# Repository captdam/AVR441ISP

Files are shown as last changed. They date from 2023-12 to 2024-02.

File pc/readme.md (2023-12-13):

# ISP PC software

This software will open a TCP server to interactive with user and a TTY (UART) connection to interactive with ISP.

## Client-side

This software use webpage to serve the client-side GUI to reduce UI related code and compute on this software. The server-side of this software will host a mini webserver on a localhost port. User can use web browser to access the client-side program.

Using webpage (HTML + CSS + JS) not only making the GUI programming easier compare to using other methods, but also give the user the ability to customlize the UI and workflow. Users are welcome to modify any of the HTML, JS and CSS files. It is also possbile to open the server port to network for remote programming.

There is no need to compile the client-side code, web browser does this on-the-fly, and they are not slow (for modern PC).

## Server

The server-side of this software is in fact a simple HTTP server and a UART translator.

GET request from client-side via XHR lets the server to return webpage related resources, such as HTML file, JS file...

POST / PUT request lets the server to translate the request from HTTP to UART and relay the request to the ISP. After ISP response, the server return the response to the client.

DELETE request halts the software.

Compile with ```gcc *.c -O2 -o isp```.

## Execute

First, connect the ISP to PC.

Execute with ```./isp tty port``` where ```tty``` is the UART device and ```port``` is the port number to open server. Example: ```./isp /dev/ttyUSB0 10086```.

Use web browser (I use Firefox for dev) and go to ```localhost:port``` where ```port``` is same as the previous step. Example: ```localhost:10086```. You may open page inspector to see some logs in console. This will send a ```GET``` request to the server to get the client-side software from the server. A blank page then displayed in the web browser, the server-side software also says "Request index page".

Click any button on this page will send ```PUT``` request to the server. The server will translate the request from HTTP to UART and send it to the ISP. After ISP response, the data from ISP in UART will be translated into HTTP response body and returned back to the client.

The first step is to use "SPI Get" to enable programming and read signature bytes from the target AVR. If the signature matches with a known one in the configuration JSON, this software will display a table of the NVME of the target AVR. Use "X READ" to read each of them (example, read hfuse), the software will read the specific data from the target AVR and display them in the table.

To porperly close the software, use the "Halt". This will send a ```DELETE``` request which request the server to exit (this performs some house-cleanning before exit). After this operation, you must restart the server-side software and refresh the client-side page to use this software again.

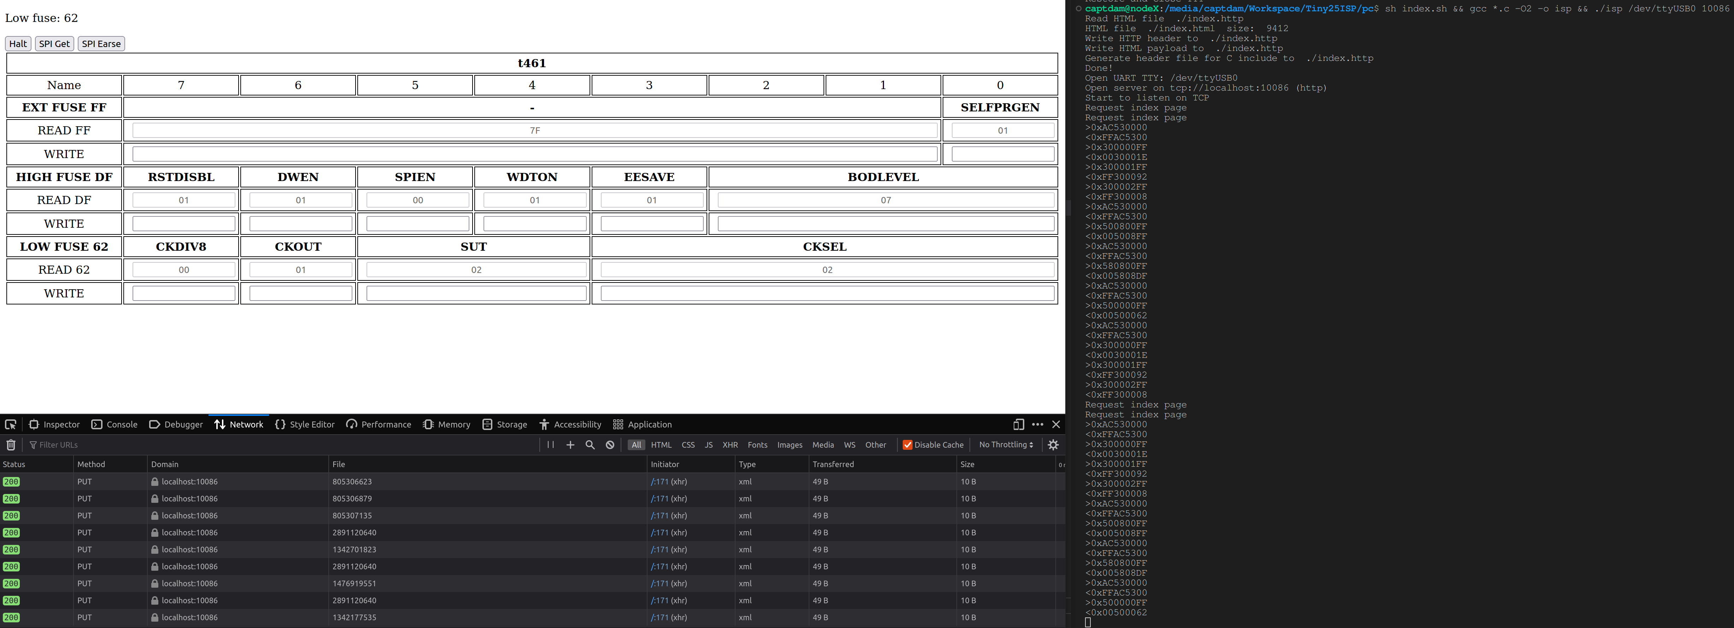
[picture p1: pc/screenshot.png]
Program running


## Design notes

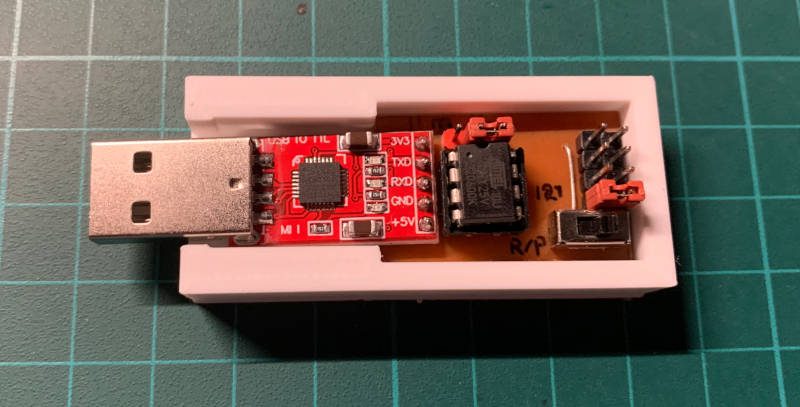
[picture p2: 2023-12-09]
isp/photo-frontside.jpeg

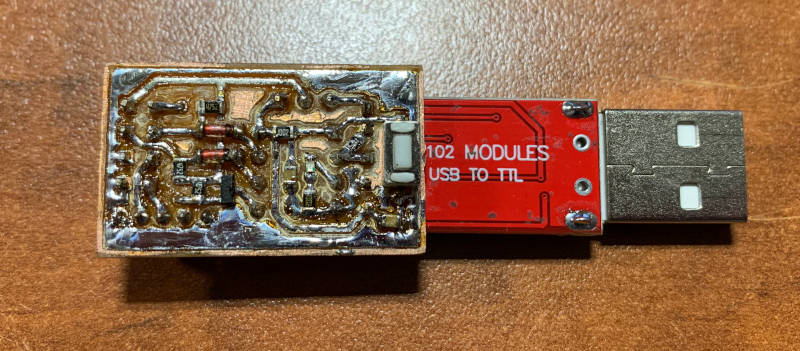
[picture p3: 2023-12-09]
isp/photo-backside.jpeg

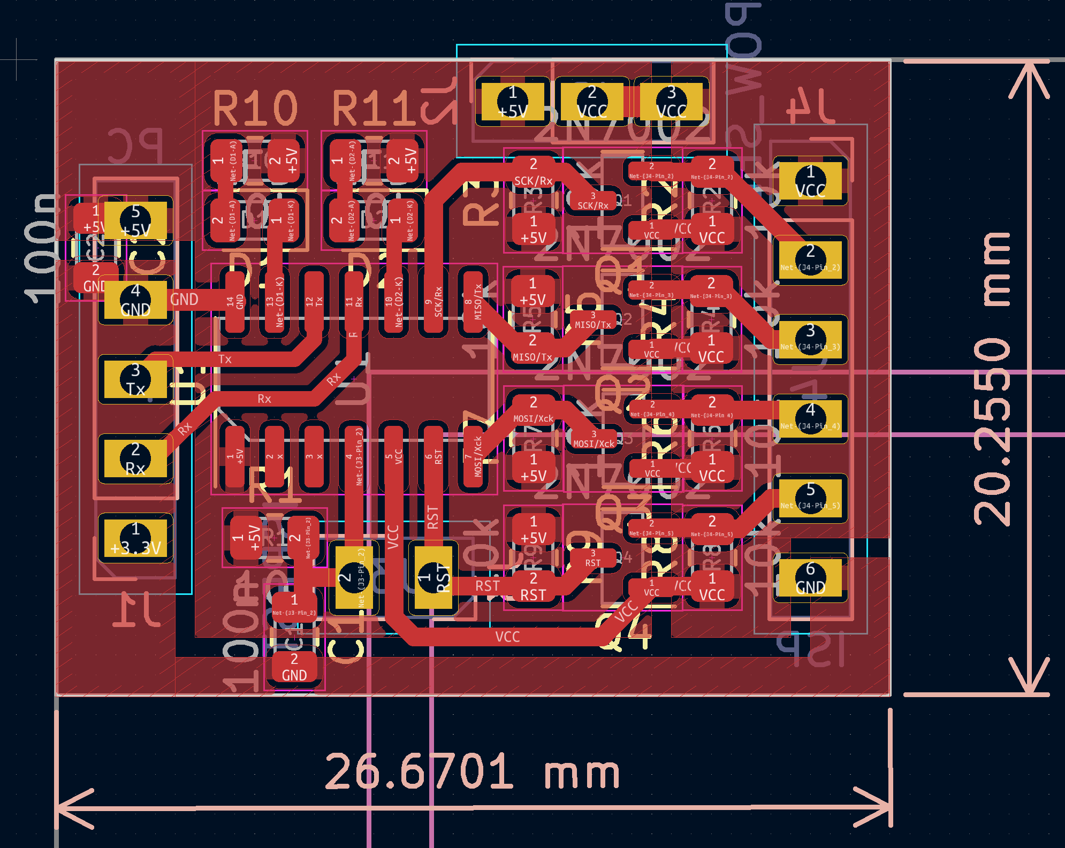
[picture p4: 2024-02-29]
isp/PCB/PCB.png

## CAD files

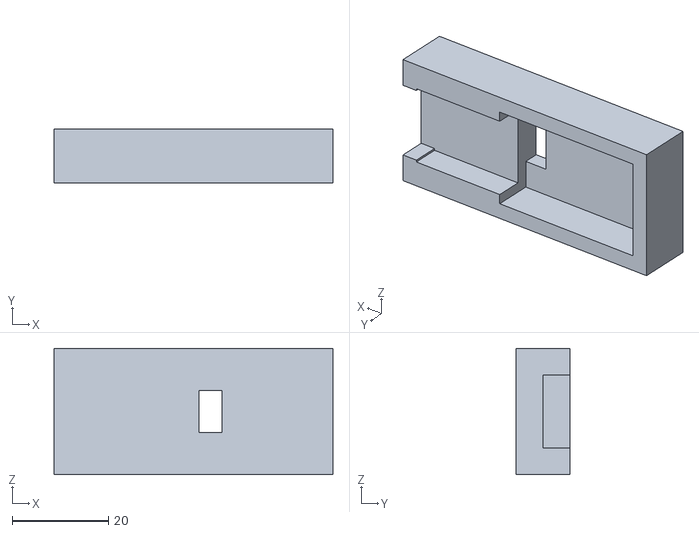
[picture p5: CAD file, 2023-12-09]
isp/Case/isp.STL
57.9 x 11.1 x 26.2

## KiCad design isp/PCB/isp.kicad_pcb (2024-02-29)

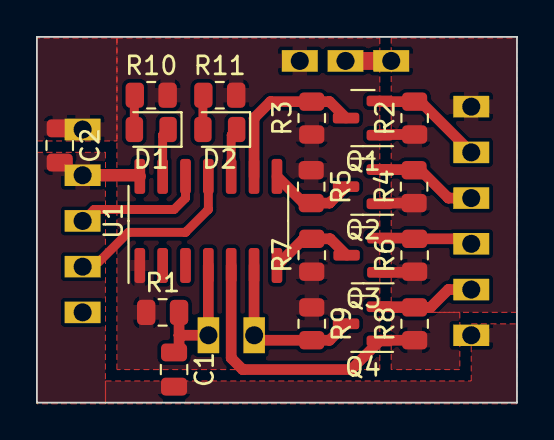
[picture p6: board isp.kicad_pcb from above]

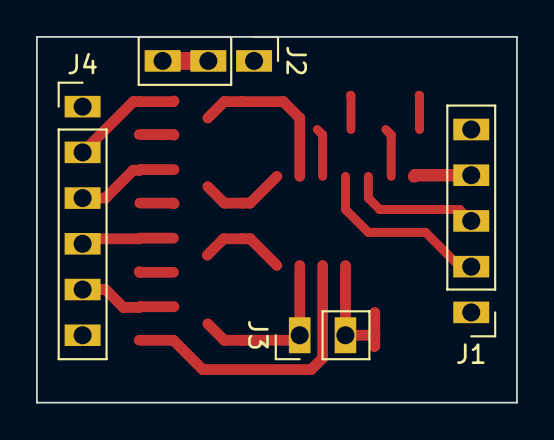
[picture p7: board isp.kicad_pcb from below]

Board: 2 copper layers, 26.7 x 20.3 mm, 24 parts (4 on the bottom side), 18 nets.

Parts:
C1, C2: 100n; C_0805_2012Metric
D1, D2: LED; LED_0805_2012Metric
J1: PC; PinHeader_1x05_P2.54mm_Vertical
J2: POW_SEL; PinHeader_1x03_P2.54mm_Vertical
J3: ISPRST; PinHeader_1x02_P2.54mm_Vertical
J4: ISP; PinHeader_1x06_P2.54mm_Vertical
Q1, Q2, Q3, Q4: 2N7002; SOT-23
R1, R2, R3, R4, R5, R6, R7, R8, R9, R10, R11: 10k; R_0805_2012Metric
U1: ATtiny841-SS; SOIC-14_3.9x8.7mm_P1.27mm

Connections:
+5V: C2.1, J1.5, J2.1, R1.1, R3.1, R5.1, R7.1, R9.1, R10.2, R11.2, U1.1 (VCC)
GND: C1.2, C2.2, J1.4, J4.6, U1.14 (GND)
MISO/Tx: Q2.3 (D), R5.2, U1.8 (PA5)
MOSI/Xck: Q3.3 (D), R7.2, U1.7 (PA6)
unnamed: D1.2 (A), R10.1
unnamed: D1.1 (K), U1.13 (AREF/PA0)
unnamed: D2.2 (A), R11.1
unnamed: D2.1 (K), U1.10 (PA3)
unnamed: C1.1, J3.2, R1.2, U1.4 (~RESET/PB3)
unnamed: J4.2, Q1.2 (S), R2.2
unnamed: J4.3, Q2.2 (S), R4.2
unnamed: J4.4, Q3.2 (S), R6.2
unnamed: J4.5, Q4.2 (S), R8.2
RST: J3.1, Q4.3 (D), R9.2, U1.6 (PA7)
Rx: J1.2, U1.11 (PA2)
SCK/Rx: Q1.3 (D), R3.2, U1.9 (PA4)
Tx: J1.3, U1.12 (PA1)
VCC: J2.2, J2.3, J4.1, Q1.1 (G), Q2.1 (G), Q3.1 (G), Q4.1 (G), R2.1, R4.1, R6.1, R8.1, U1.5 (PB2)

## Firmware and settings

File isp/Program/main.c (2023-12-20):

#define PIN_DI 0
#define PIN_DO 1
#define PIN_CK 2
#define PIN_UART 3
#define PIN_LED 4
#define UART_DELAY 69 // 8MHz / 115200BAUD = 69.44 cycles => Trim to 7.9488MHz

#include <avr/io.h>

uint8_t spi(uint8_t data);
void uart_tx(uint8_t data);
uint8_t uart_rx();

void main(void) {
	PORTB = (1<<PIN_UART) | (1<<PIN_DI); // Pull-up for idle state, pull-up for input level shifter
	DDRB = (1<<PIN_CK) | (1<<PIN_DO); // SPI output

	TCCR0A = (2<<CS00); // CTC mode with OCR0A
	OCR0A = UART_DELAY; // Output BAUD
	OCR0B = UART_DELAY >> 1; // Sample at middle

	for (uint8_t d;;) {
		d = uart_rx();
		d = spi(d);
		uart_tx(d);
	}
}

uint8_t spi(uint8_t data) {
	TCNT0 = 0; // Reset and start timer at clk/1 (1MHz)
	TIFR = (1<<OCF0A);
	TCCR0B = (1<<CS00);

	USIDR = data;
	USISR = (1<<USIOIF);
	do {
		while (!( TIFR & (1<<OCF0A) ));
		TIFR = (1<<OCF0A);
		USICR = (1<<USIWM0) | (1<<USICS1) | (1<<USICLK) | (1<<USITC);
	} while (!( USISR & (1<<USIOIF) ));
	
	TCCR0B = (0<<CS00);
	return USIDR;
}

/* Low speed UART TX */
void uart_tx(uint8_t data) {
	TCNT0 = 0; // Reset and start timer, UART drive mode
	TIFR = (1<<OCF0A);
	TCCR0B = (1<<CS00);
	DDRB |= (1<<PIN_UART);

	PORTB &= ~(1<<PIN_UART); // 1 start bit
	while (!( TIFR & (1<<OCF0A) ));
	TIFR = (1<<OCF0A);
	
	for (uint8_t c = 8; c; c--) { // 8 data bits
		if (data & 1) {
			PORTB |= (1<<PIN_UART);
		} else {
			PORTB &= ~(1<<PIN_UART);
		}
		data = data >> 1;
		while (!( TIFR & (1<<OCF0A) ));
		TIFR = (1<<OCF0A);
	}

	PORTB |= (1<<PIN_UART); // 2 stop bits
	while (!( TIFR & (1<<OCF0A) ));
	TIFR = (1<<OCF0A);
	while (!( TIFR & (1<<OCF0A) ));
	
	DDRB &= ~(1<<PIN_UART); // Switch back to input mode & Stop timer to save energy
	TCCR0B = (0<<CS00);
}

/* Low speed UART RX, polling, not for time critical task */
uint8_t uart_rx() {
	TCNT0 = 0; // Reset timer
	TIFR = (1<<OCF0B);
	uint8_t data;

	while (PINB & (1<<PIN_UART)); // Waiting for start bit (low) to start timer
	TCCR0B = (1<<CS00);

	for (uint8_t c = 9; c; c--) { // Read 1 start bit (discard) and 8 data bits
		while (!( TIFR & (1<<OCF0B) ));
		TIFR = (1<<OCF0B);
		data = data >> 1;
		if (PINB & (1<<PIN_UART))
			data |= 0x80;
	}

	while (!( TIFR & (1<<OCF0B) )); // Since Tx and Rx share the same line
	TIFR = (1<<OCF0B);
	while (!( TIFR & (1<<OCF0B) )); // Wait for 2.5 stop bits to prevent conflict (sample point for 3rd stop bit)
	TIFR = (1<<OCF0B);
	while (!( TIFR & (1<<OCF0B) ));

	TCCR0B = (0<<CS00); // Stop timer to save energy
	return data;
}

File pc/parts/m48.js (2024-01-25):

avr_sig['1E9205'] = ['m48a', 'm48', 2048, 256, 32, 64, 4, 64, 5, 4];
avr_sig['1E920A'] = ['m48pa', 'm48', 2048, 256, 32, 64, 4, 64, 5, 4];
avr_sig['1E930A'] = ['m88a', 'm88', 4096, 512, 32, 128, 4, 128, 5, 4];
avr_sig['1E930F'] = ['m88pa', 'm88', 4096, 512, 32, 128, 4, 128, 5, 4];
avr_sig['1E9406'] = ['m168a', 'm88', 8192, 512, 64, 128, 4, 128, 5, 4];
avr_sig['1E940B'] = ['m168pa', 'm88', 8192, 512, 64, 128, 4, 128, 5, 4];
//avr_sig['1E9514'] = ['m328', 'm328', 16384, 1024, 64, 256, 4, 256, 5, 4];
avr_sig['1E9514'] = ['m328', 'm328', 2048, 256, 32, 64, 4, 64, 5, 4];
avr_sig['1E950F'] = ['m328p', 'm328', 16384, 1024, 64, 256, 4, 256, 5, 4];

avr_nvme.m48 = {
	"lock": {"LB_PLACEHOLDER": [6, 63], "LB": [2, 3]},
	"efuse": {"EFUSE_PLACEHOLDER": [7, 127], "SELFPRGEN": [1, 1]},
	"hfuse": {"RSTDISBL": [1, 1], "DWEN": [1, 1], "SPIEN": [1, 0], "WDTON": [1, 1], "EESAVE": [1, 1], "BODLEVEL": [3, 7]},
	"lfuse": {"CKDIV8": [1, 0], "CKOUT": [1, 1], "SUT": [2, 2], "CKSEL": [4, 2]},
	'desc': {
		'LB_PLACEHOLDER': {'63':'RESERVED'},
		'LB': {
			'0': 'Flash & EEP programming + verification disabled',
			'1': 'Flash & EEP programming disabled',
			'3': 'Flash & EEP unlocked'
		},
		'EFUSE_PLACEHOLDER': {'127':'RESERVED'},
		'SELFPRGEN': {
			'0': 'Self programming enabled',
			'1': 'Self programming disabled'
		},
		'RSTDISBL': {
			'0': 'Reset pin as GPIO (use HV to reset)',
			'1': 'Reset pin as reset'
		},
		'DWEN': {
			'0': 'Debug wire enabled',
			'1': 'Debug wire disabled'
		},
		'SPIEN': {
			'0': 'Serial programming enabled',
			'1': 'Serial programming disabled'
		},
		'WDTON': {
			'0': 'Watchdog always on',
			'1': 'Watchdog not on'
		},
		'EESAVE': {
			'0': 'Preserve EEPROM during chip earse',
			'1': 'Chip earse will earse EEPROM'
		},
		'BODLEVEL': {
			'4': '4.1V / 4.3V / 4.5V',
			'5': '2.5V / 2.7V / 2.9V',
			'6': '1.7V / 1.8V / 2.0V',
			'7': 'Disabled'
		},
		'CKDIV8': {
			'0': 'CPU speed at CLK/8',
			'1': 'CPU speed at CLK'
		},
		'CKOUT': {
			'0': 'Output clock signal on pin',
			'1': 'Do not output clock'
		},
		'SUT': {
			'0': 'Fast start-up',
			'1': '4ms delay',
			'2': '64ms delay'
		},
		'CKSEL': {
			'0': 'External clock',
			'2': '8MHz internal RC',
			'3': '128kHz internal',
			'4': '32kHz crystal, fast start-up',
			'5': '32kHz crystal, slow start-up',
			'6': 'Full swing crystal (see doc p.40)',
			'7': 'Full swing crystal (see doc p.40)',
			'8': '0.4-0.9 MHz external crystal, fast start-up',
			'9': '0.4-0.9 MHz external crystal, slow start-up',
			'10': '0.9-3.0 MHz external crystal, fast start-up',
			'11': '0.9-3.0 MHz external crystal, slow start-up',
			'12': '3-8 MHz external crystal, fast start-up',
			'13': '3-8 MHz external crystal, slow start-up',
			'14': '8-16 MHz external crystal, fast start-up',
			'15': '8-16 MHz external crystal, slow start-up'
		}
	},
	'doc': 'https://ww1.microchip.com/downloads/aemDocuments/documents/MCU08/ProductDocuments/DataSheets/ATmega48A-PA-88A-PA-168A-PA-328-P-DS-DS40002061B.pdf'
};

avr_nvme.m88 = {
	"lock": {"LB_PLACEHOLDER": [2, 3], "BLB1": [2, 3], "BLB0": [2, 3], "LB": [2, 3]},
	"efuse": {"EFUSE_PLACEHOLDER": [5, 31], "BOOTSZ": [2, 0], "BOOTRST": [1, 1]},
	"hfuse": avr_nvme.m48.hfuse,
	"lfuse": avr_nvme.m48.lfuse,
	'desc': {
		'LB_PLACEHOLDER': {'3':'RESERVED'},
		'BLB1': {
			'0': 'No SPM to Application, No LPM from Bootloader to Application',
			'1': 'No LPM from Bootloader to Application',
			'2': 'No SPM to Application',
			'3': 'Free SPM / LPM access to Application'
		},
		'BLB0': {
			'0': 'No SPM to Bootloader, No LPM from Application to Bootloader',
			'1': 'No LPM from Application to Bootloader',
			'2': 'No SPM to Bootloader',
			'3': 'Free SPM / LPM access to Bootloader'
		},
		'LB': avr_nvme.m48.desc.LB,
		'EFUSE_PLACEHOLDER': {'31':'RESERVED'},
		'BOOTSZ': {
			'0': '2048 words Bootloader',
			'1': '1024 words Bootloader',
			'2': '512 words Bootloader',
			'3': '256 words Bootloader'
		},
		'BOOTRST': {
			'0': 'Reset from Bootloader section',
			'1': 'Reset from Application section'
		},
		'RSTDISBL': avr_nvme.m48.desc.RSTDISBL,
		'DWEN': avr_nvme.m48.desc.DWEN,
		'SPIEN': avr_nvme.m48.desc.SPIEN,
		'WDTON': avr_nvme.m48.desc.WDTON,
		'EESAVE': avr_nvme.m48.desc.EESAVE,
		'BODLEVEL': avr_nvme.m48.desc.BODLEVEL,
		'CKDIV8': avr_nvme.m48.desc.CKDIV8,
		'CKOUT': avr_nvme.m48.desc.CKOUT,
		'SUT': avr_nvme.m48.desc.SUT,
		'CKSEL': avr_nvme.m48.desc.CKSEL
	},
	'doc': avr_nvme.m48.doc
};

avr_nvme.m328 = {
	"lock": avr_nvme.m88.lock,
	"efuse": {"EFUSE_PLACEHOLDER": [5, 31], "BODLEVEL": [3, 7]},
	"hfuse": {"RSTDISBL": [1, 1], "DWEN": [1, 1], "SPIEN": [1, 0], "WDTON": [1, 1], "EESAVE": [1, 1], "BOOTSZ": [2, 0], "BOOTRST": [1, 1]},
	"lfuse": avr_nvme.m48.lfuse,
	"desc": {
		'LB_PLACEHOLDER': avr_nvme.m88.desc.LB_PLACEHOLDER,
		'BLB1': avr_nvme.m88.desc.BLB1,
		'BLB0': avr_nvme.m88.desc.BLB0,
		'LB': avr_nvme.m48.desc.LB,
		'EFUSE_PLACEHOLDER': avr_nvme.m88.desc.EFUSE_PLACEHOLDER,
		'BODLEVEL': avr_nvme.m48.desc.BODLEVEL,
		'RSTDISBL': avr_nvme.m48.desc.RSTDISBL,
		'DWEN': avr_nvme.m48.desc.DWEN,
		'SPIEN': avr_nvme.m48.desc.SPIEN,
		'WDTON': avr_nvme.m48.desc.WDTON,
		'EESAVE': avr_nvme.m48.desc.EESAVE,
		'BOOTSZ': avr_nvme.m88.desc.BOOTSZ,
		'BOOTRST': avr_nvme.m88.desc.BOOTRST,
		'CKDIV8': avr_nvme.m48.desc.CKDIV8,
		'CKOUT': avr_nvme.m48.desc.CKOUT,
		'SUT': avr_nvme.m48.desc.SUT,
		'CKSEL': avr_nvme.m48.desc.CKSEL
	},
	'doc': avr_nvme.m48.doc
};

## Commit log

2023-11-29 Upload PCB and program
    [isp.kicad_pcb, isp.kicad_sch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]
2023-12-04 Server: change flow. Client: create ISP getters
2023-12-05 Optimize ISP circuit - Add ISP reset button and target enable SW - Change ISP output level shifter from NMOS to diode (save space & cost) - Rearrang PCB to save size, some SMD on back can overlap wit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
    [isp.kicad_pcb, isp.kicad_sch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]
2023-12-09 Update PC server side: send 4 byte a time. AVR SPI cmd format is always 4 byte. For TPI (12bits), we can send 2 wors / 4 bytes, padding with idle bits
2023-12-09 Update ISP program. - Decrease SPI speed for stable communication. - Use internal pull-up for SPI input (change from circuit).
2023-12-09 Upload actual PCB and case photp and model file
    [isp.STL]
2023-12-14 Working on GUI - GUI layout - Get Model (signature) - Get Fuse - Get Lock bits
2023-12-17 Add fuse/lock read/write function with check before write. Add new parts.
2023-12-20 ISP speed change: 9600 --> 115200 - Increase speed: Data stream (EEPROM/Flash) transfer at 9600BAUD is too slow (9600 only good for fuse). - Reduce resistor (50k --> 5k), Pull-up time too long for 50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
    [isp.kicad_pcb, isp.kicad_sch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]
2024-02-29 New PCB design: Switch from tiny25 to tiny441/841
    [isp.kicad_pcb, isp.kicad_sch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]
